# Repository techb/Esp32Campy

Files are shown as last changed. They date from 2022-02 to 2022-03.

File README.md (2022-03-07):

# Esp32Campy
Python implementation for a WebSocket server handling ESP32 Cam module streams. Flask server to handle front-end and house the JS used that does most of the WebSocket work you see. Since this is using a server to handle everything, the limit for concurrent connections, all receiving the live stream and control access, is high.

**This is a fun hobby project and not meant for use in production environments.**

| ABV | == | Abbreviation |
|-----|---|---|
| ESP | == | ESP Cam Module |
| WS  | == | Web Socket |
| FS  | == | Flask Server |

- **WS Server**: Handles the websocket connections. Tracks currently connected clients and removes them when their connections drop. When the WS server receives  messages/data it will echo/resend it to all other connected clients. I wrote it where you need to put in the WS address:port incase you have multiple devices running at once or multi-client connectons. You can connect to the WS of each bot/device/ESP on the network if you know the IP:PORT address.

- **Flask**: Simple flask server handling front-end connections. Serves a single html page containing an img tag for the video data and buttons to control the ESP. This is split up into 3 (three) main places: `static`, `templates`, `classes/FlaskServer.py`. Each containing the respective code. This is the same IP address as the WS server, but a different port.
  - `static`: JavaScript and CSS
  - `templates`: Flask HTML templates
  - `classes/FlaskServer.py`: Flask Server Class

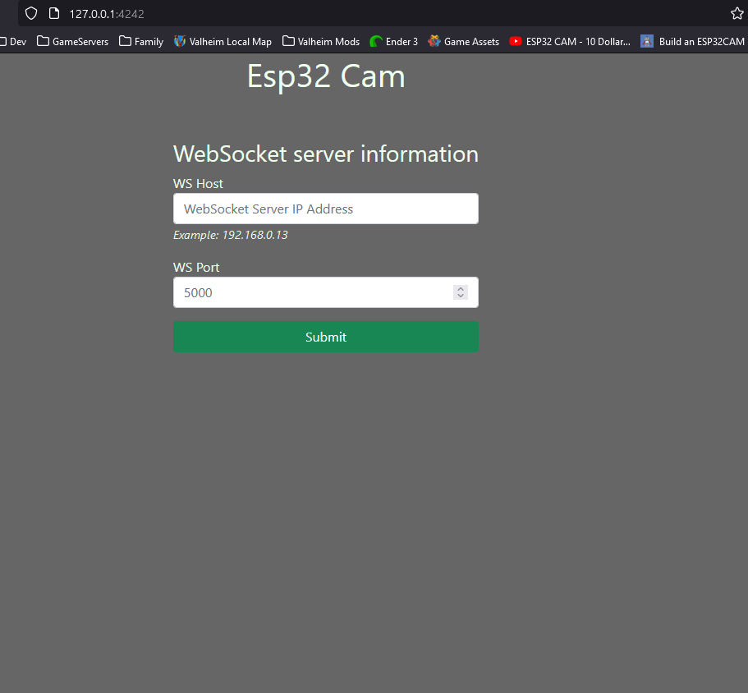
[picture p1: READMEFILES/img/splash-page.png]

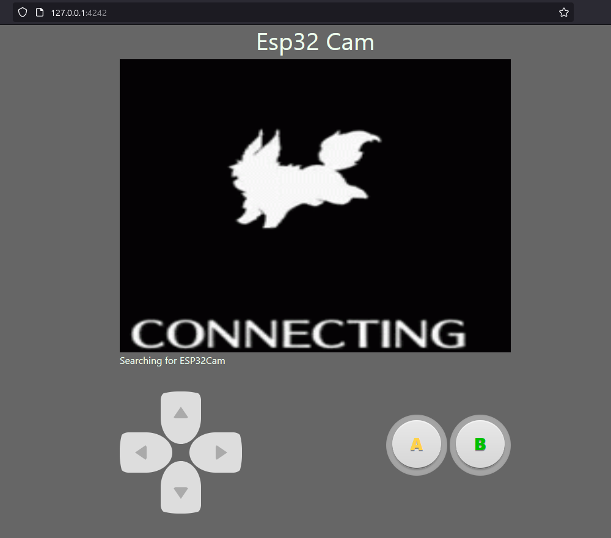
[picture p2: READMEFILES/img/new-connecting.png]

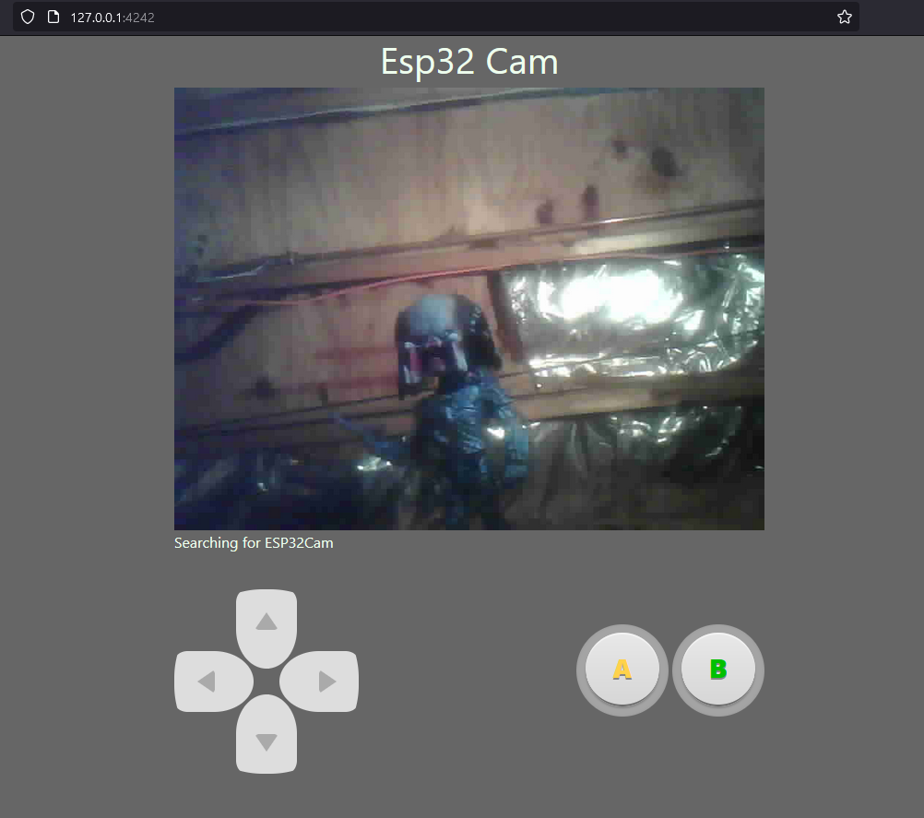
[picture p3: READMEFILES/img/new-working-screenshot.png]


## Software Requirements
- websockets: https://github.com/aaugustin/websockets
- Flask: https://flask.palletsprojects.com/

## Firmware Requirements
- ArduinoJson: https://arduinojson.org/
- Arduino Websockets: https://github.com/gilmaimon/ArduinoWebsockets
- ESP32 Libs & Board manager: https://randomnerdtutorials.com/installing-the-esp32-board-in-arduino-ide-windows-instructions/

## BOM
- ESP32 Cam: https://www.amazon.com/dp/B07S5PVZKV
- USB to FTDI: https://www.sparkfun.com/products/9716
  - You'll need drivers: https://ftdichip.com/drivers/vcp-drivers/
- N20 Motors X2: https://www.amazon.com/gp/product/B07SQ4TV2T
- H-Bridge: https://www.amazon.com/Aideepen-Driver-H-Bridge-Replace-Stepper/dp/B075S368Y2/
- 18640 Batteries X2: https://www.amazon.com/LCLEBM-3400mAh-Battery-Spotlight-Flashlight/dp/B08H1NZLY7

## 3D Print
**--- WARNING! ---**

The .gcode file provided uses a BLTouch.
If you don't use a BLTouch you will need to remove `G29 ; Level bed` in the .gcode file.
There is also OctoLapse comments, those can be ignored if not using OctoLapse, or removed if you prefer your own config.

**----------------**
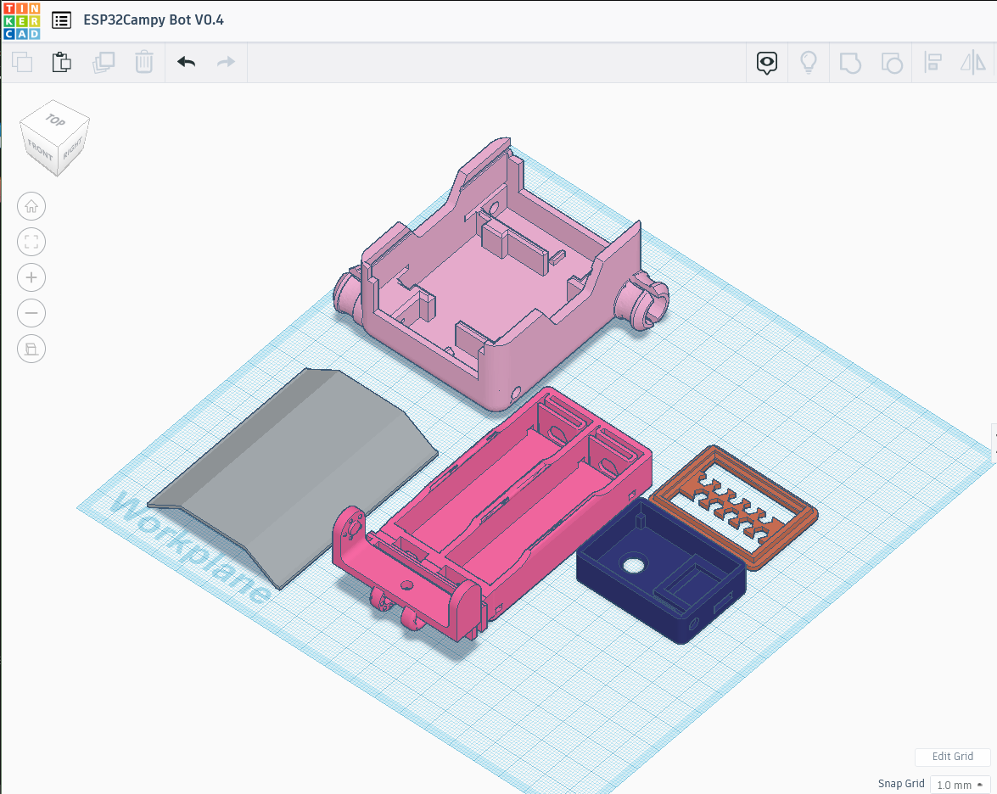
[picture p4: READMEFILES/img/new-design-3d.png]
stl preview 10 hours


#### Remixed From
- cam case: https://www.thingiverse.com/thing:4107609
- 18640 battery holder: https://www.thingiverse.com/thing:2339441
- SMARS robot: https://www.thingiverse.com/thing:2662828

## Schematics
EasyEDA somehow did not save my project... This is the only thing I have from it currently. It is simple enough though. H-Bridge for the motors, voltage regulation, and some optional stuff to make programming easier but not needed (set up for the next project teehee). 

Tripple check connections and cross reference always, I am but a simple man and mess up a lot lol. **Pay attention to orientation and GPIO**
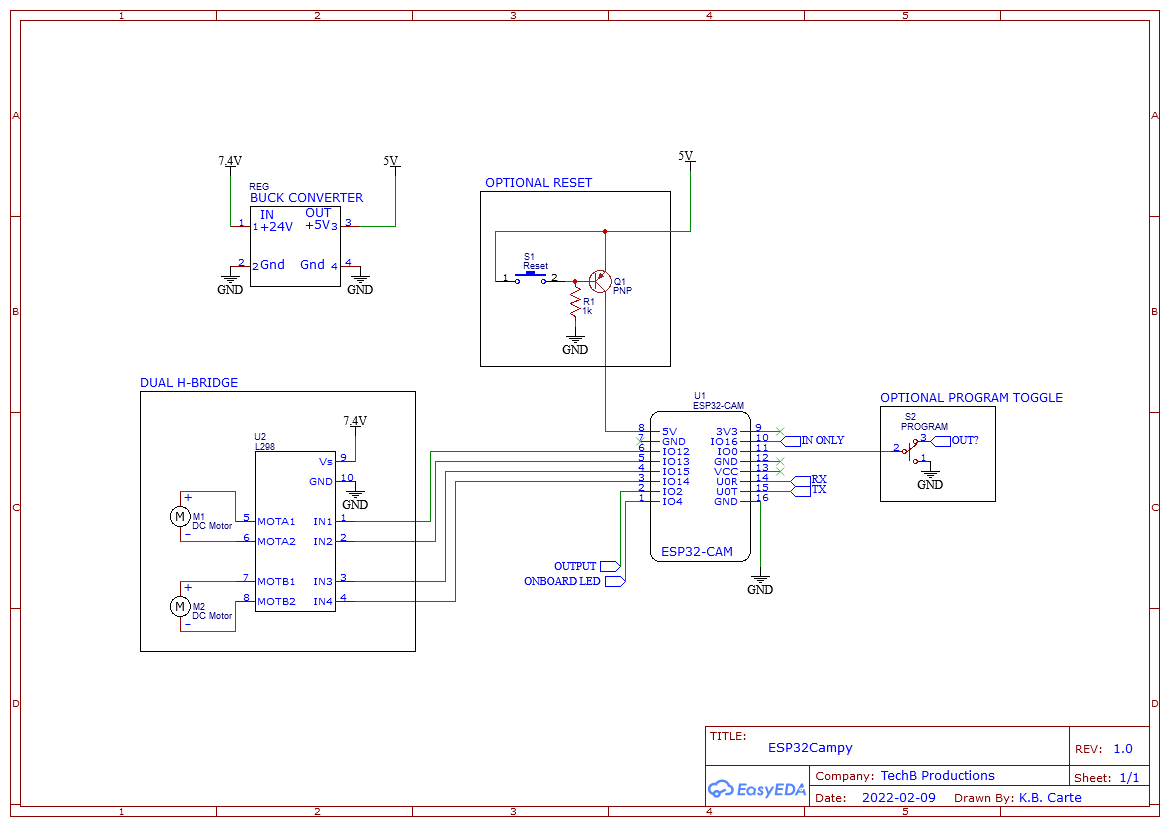
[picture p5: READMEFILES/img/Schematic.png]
image of schematics


## Run
- `$ git clone git@github.com:techb/Esp32Campy.git`
- Ensure you have the required libraries installed for your Arduino IDE
- Upload the `firmware/` code to the ESP32 Cam module via FTDI
  - Change the wifi credentials to be the same network the servers are running on. 
  - You will probably need to make a new Arduino project and save and/or copy the files.
- `$ python -m venv venv`
- `$ venv\Scripts\activate` :: Windows 11/10
  - activating env is dependent on [your OS](https://www.infoworld.com/article/3239675/virtualenv-and-venv-python-virtual-environments-explained.html)
- `$(venv) pip install -r requirements.txt`
- `$(venv) python servers.py`
- Visit your server's IP, if on _this machine/local_ you can use the loopback address
  - default front-end port: `4242`
  - http://127.0.0.1:4242
  - to change default port: edit (WSPORT, FSPORT) in `servers.py` respectively.

## To Do
- Build/Project blog write up
- Clean 3D print files
- Fix mobile
- Hide/Show connecting on disconnect/reconnect of ESP
- Add hosts file for blah.local addresses
- V2 use UART & arduino controlling the low level bot controls like movement. Stay REST-ish, realtime req->parse->bot control

## References
- websockets: https://github.com/aaugustin/websockets
  - docs: https://websockets.readthedocs.io/en/stable/
- great vid, he has more too: https://www.youtube.com/watch?v=SfQd1FdcTlI
- arduino ws broadcast example: https://shorturl.at/akAFG
- loading gif: https://boingboing.net/2015/10/18/loadingicon-trippy-looping-gi.html
- d-pad buttons: https://saruwakakun.com/en/css3-buttons
- AB/XY buttons: https://codepen.io/tswone/pen/GLzZLd
- Bootstrap CSS: https://getbootstrap.com/
- Gamepad support: https://w3c.github.io/gamepad/#remapping
- Gamepad tutorial: https://beej.us/blog/data/javascript-gamepad/
- RX GPIO 3 is always and only an input: https://electronics.stackexchange.com/a/445636

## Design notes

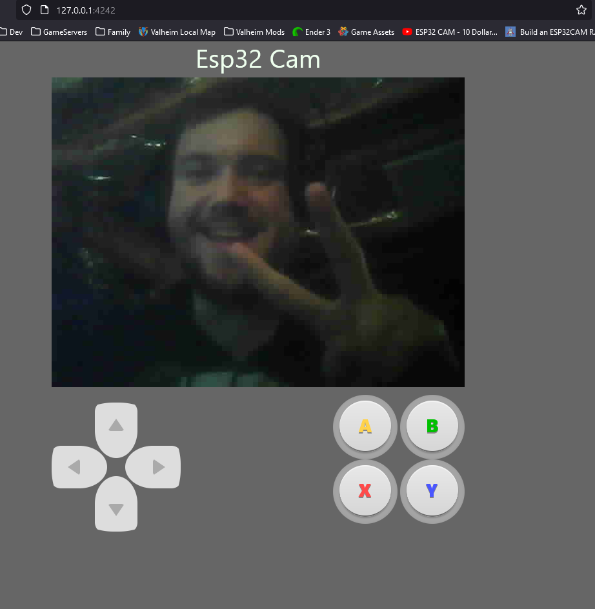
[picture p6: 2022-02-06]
READMEFILES/img/working-stream-low-rez.png

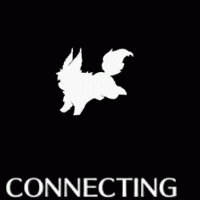
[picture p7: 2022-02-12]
READMEFILES/img/connecting.gif

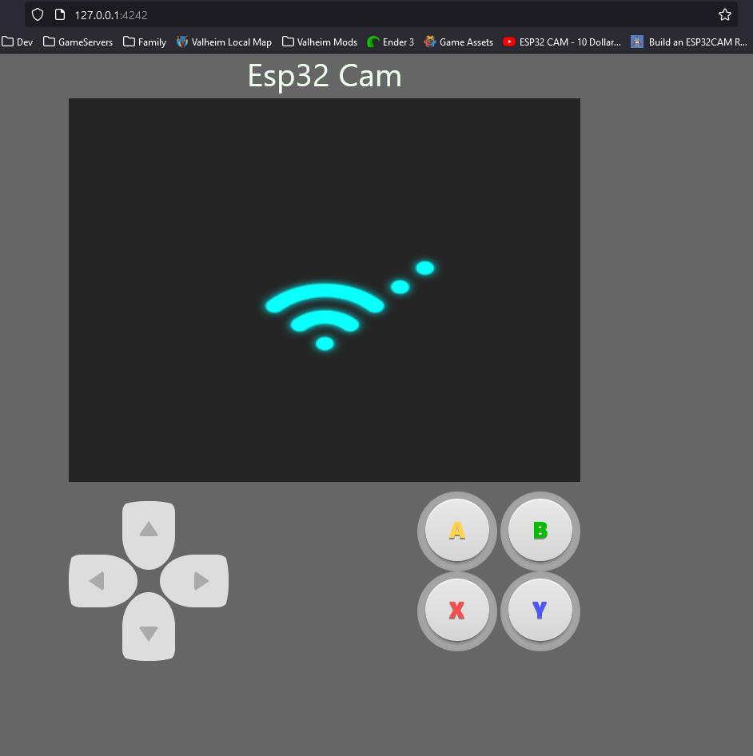
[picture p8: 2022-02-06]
READMEFILES/img/waiting-on-espcam.png

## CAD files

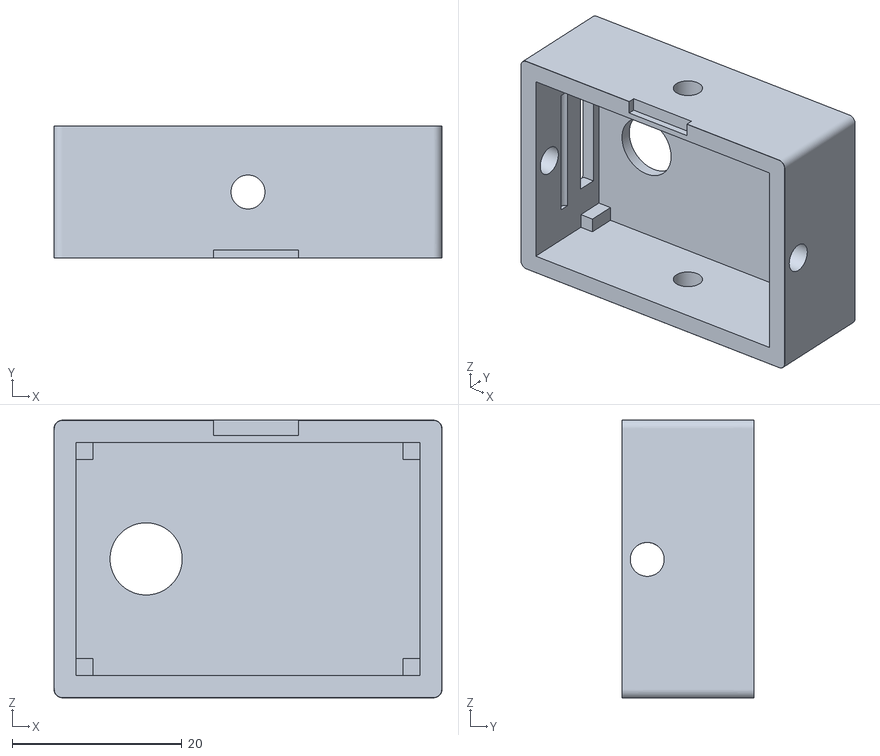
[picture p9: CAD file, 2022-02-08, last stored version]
3DPrint/ESPBot-Cam-Case.stl
45.7 x 15.6 x 32.7

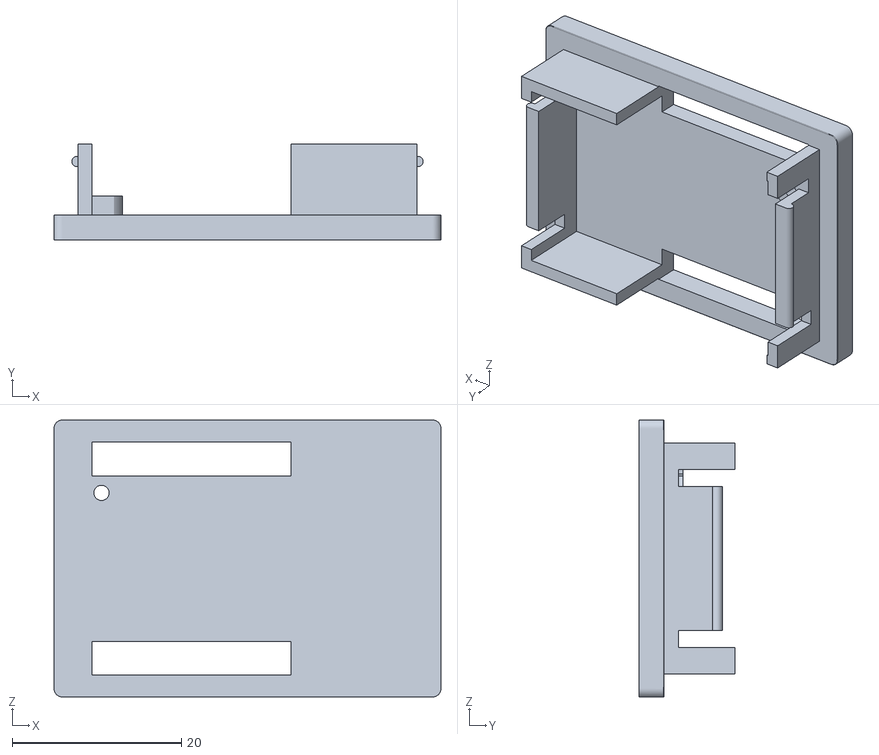
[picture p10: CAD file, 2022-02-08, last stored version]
3DPrint/ESPBot-Cam-Lid.stl
45.7 x 11.4 x 32.7

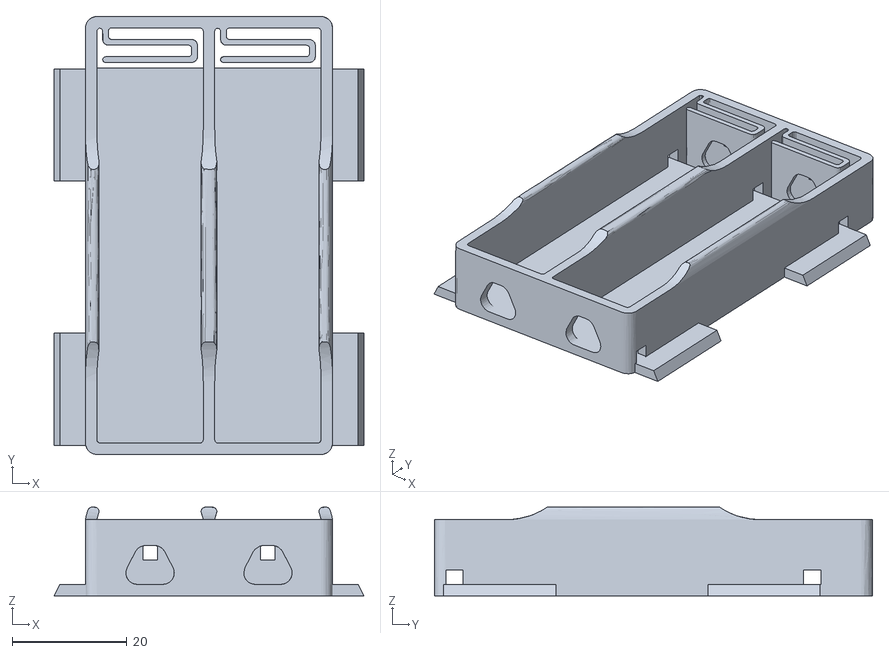
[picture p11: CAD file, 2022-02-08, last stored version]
3DPrint/ESPBot-18650-Holder-X2.stl
53.9 x 76.2 x 15.4

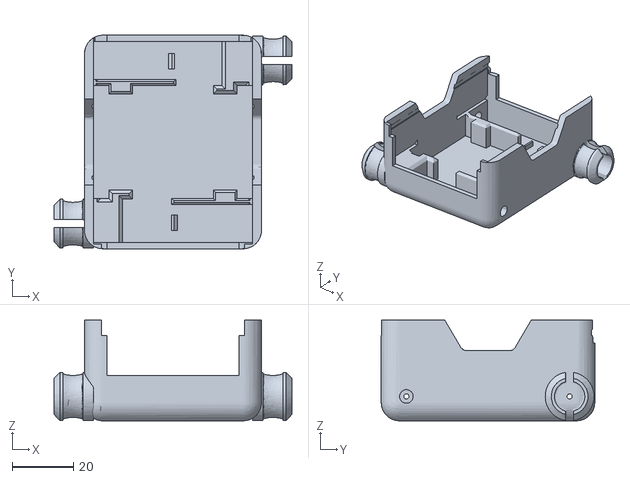
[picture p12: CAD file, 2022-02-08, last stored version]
3DPrint/ESPBot-SMARS-Body.stl
78.0 x 70.0 x 33.0

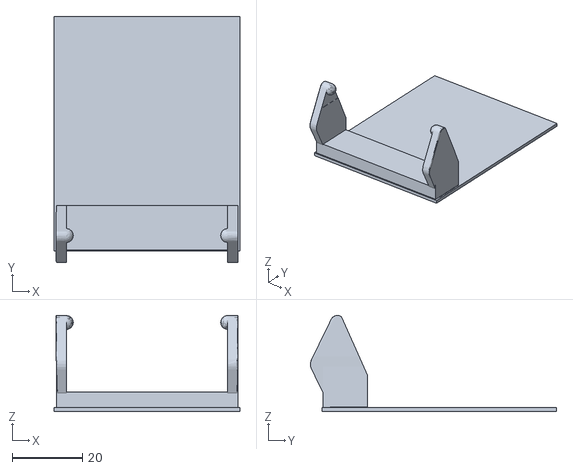
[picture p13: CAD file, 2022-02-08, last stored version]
3DPrint/ESPBot-Swivel-Cam-Holder.stl
53.0 x 70.1 x 27.4

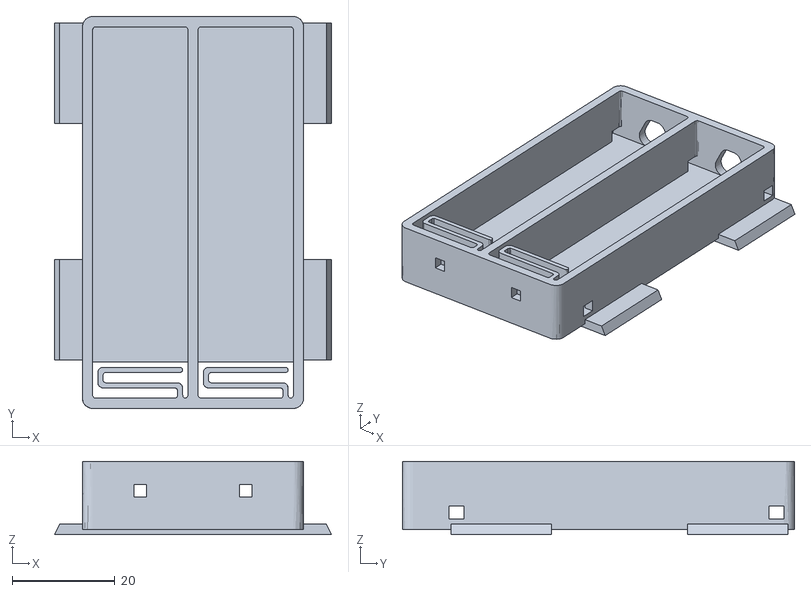
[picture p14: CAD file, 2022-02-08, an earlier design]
3DPrint/ESPBot-18650-Holder-X2-old.stl
53.9 x 76.2 x 14.2

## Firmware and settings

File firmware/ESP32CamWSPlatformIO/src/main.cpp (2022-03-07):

#include "esp_camera.h"
#include <WiFi.h>
#include <Arduino.h>
#include <ArduinoWebsockets.h>
#include <ArduinoJson.h>

// specific to my board yours might be different if
// not using the board listed in the BOM
#define CAMERA_MODEL_AI_THINKER
#include "camera_pins.h"

// network creds and server info
const char *ssid = "Wu Tang LAN";
const char *password = "PostitKnockers";
const char *websocket_server_host = "192.168.0.18";
const uint16_t websocket_server_port = 5000;

// create buffer to receive data comming from other ws clients
StaticJsonDocument<255> jsonBuffer;

// init the websocket client that connects to the ws server
using namespace websockets;
WebsocketsClient client;

// quick and dirty for now
// needs refactor and PWM for movement
void forward()
{
  digitalWrite(12, HIGH);
  digitalWrite(13, LOW);
  digitalWrite(15, HIGH);
  digitalWrite(14, LOW);
}
void reverse()
{
  digitalWrite(12, LOW);
  digitalWrite(13, HIGH);
  digitalWrite(15, LOW);
  digitalWrite(14, HIGH);
}
void hault()
{
  digitalWrite(12, LOW);
  digitalWrite(13, LOW);
  digitalWrite(15, LOW);
  digitalWrite(14, LOW);
}
void left()
{
  digitalWrite(12, LOW);
  digitalWrite(13, HIGH);
  digitalWrite(15, HIGH);
  digitalWrite(14, LOW);
}
void right()
{
  digitalWrite(12, HIGH);
  digitalWrite(13, LOW);
  digitalWrite(15, LOW);
  digitalWrite(14, HIGH);
}
void a_button_on()
{
  digitalWrite(2, HIGH);
}
void a_button_off()
{
  digitalWrite(2, LOW);
}
void b_button_on()
{
  digitalWrite(4, HIGH);
}
void b_button_off()
{
  digitalWrite(4, LOW);
}

void setup()
{
  Serial.begin(115200);
  // Serial.setDebugOutput(true);

  // set camera pins and settings
  camera_config_t config;
  config.ledc_channel = LEDC_CHANNEL_0;
  config.ledc_timer = LEDC_TIMER_0;
  config.pin_d0 = Y2_GPIO_NUM;
  config.pin_d1 = Y3_GPIO_NUM;
  config.pin_d2 = Y4_GPIO_NUM;
  config.pin_d3 = Y5_GPIO_NUM;
  config.pin_d4 = Y6_GPIO_NUM;
  config.pin_d5 = Y7_GPIO_NUM;
  config.pin_d6 = Y8_GPIO_NUM;
  config.pin_d7 = Y9_GPIO_NUM;
  config.pin_xclk = XCLK_GPIO_NUM;
  config.pin_pclk = PCLK_GPIO_NUM;
  config.pin_vsync = VSYNC_GPIO_NUM;
  config.pin_href = HREF_GPIO_NUM;
  config.pin_sscb_sda = SIOD_GPIO_NUM;
  config.pin_sscb_scl = SIOC_GPIO_NUM;
  config.pin_pwdn = PWDN_GPIO_NUM;
  config.pin_reset = RESET_GPIO_NUM;
  config.xclk_freq_hz = 10000000;
  config.pixel_format = PIXFORMAT_JPEG;

  // init with high specs to pre-allocate larger buffers
  config.frame_size = FRAMESIZE_VGA;
  config.jpeg_quality = 40;
  config.fb_count = 2;

  // camera init
  esp_err_t err = esp_camera_init(&config);
  if (err != ESP_OK)
  {
    Serial.printf("Camera init failed with error 0x%x", err);
    return;
  }

  // connect to wifi
  WiFi.begin(ssid, password);
  while (WiFi.status() != WL_CONNECTED)
  {
    delay(500);
    Serial.print(".");
  }
  Serial.println("");
  Serial.println("WiFi connected");

  // connect to websocket
  Serial.println("Attempting WebSocket Connection");
  while (!client.connect(websocket_server_host, websocket_server_port, "/"))
  {
    delay(500);
    Serial.print(".");
  }
  Serial.println("Websocket Connected!");

  int res = 0;
  sensor_t *s = esp_camera_sensor_get();
  res = s->set_framesize(s, (framesize_t)9);

  // handle json data from web interface
  // handle_json is the callback where the actual,
  //   logic lives when recieving websocket messages
  // the auto formatting on save, is ugly af...
  client.onMessage([](WebsocketsMessage msg)
                   {
    String raw_data = msg.data();
    handle_json(raw_data); });

  pinMode(12, OUTPUT); // IN1 MA
  pinMode(13, OUTPUT); // IN2 MA
  pinMode(15, OUTPUT); // IN3 MB
  pinMode(14, OUTPUT); // IN4 MB
  pinMode(2, OUTPUT);  // A
  pinMode(4, OUTPUT);  // B

  // set everything low so the bot doesn't go crazy on startup
  digitalWrite(12, LOW);
  digitalWrite(13, LOW);
  digitalWrite(15, LOW);
  digitalWrite(14, LOW);
  digitalWrite(2, LOW);
  digitalWrite(4, LOW);
}

// handle incoming websocket messages
void handle_json(String raw_data)
{
  DeserializationError error = deserializeJson(jsonBuffer, raw_data);
  if (error)
  {
    Serial.print(F("deserializeJson() failed: "));
    Serial.println(error.f_str());
    return;
  }

  // quick and dirty for now
  // needs refactor
  const char *message = jsonBuffer["message"];

  // check message sent and deligate functions to execute
  if (strcmp(message, "forward") == 0)
  {
    forward();
  }
  if (strcmp(message, "reverse") == 0)
  {
    reverse();
  }
  if (strcmp(message, "hault") == 0)
  {
    hault();
  }
  if (strcmp(message, "left") == 0)
  {
    left();
  }
  if (strcmp(message, "right") == 0)
  {
    right();
  }

  if (strcmp(message, "AON") == 0)
  {
    a_button_on();
  }
  if (strcmp(message, "AOFF") == 0)
  {
    a_button_off();
  }
  if (strcmp(message, "BON") == 0)
  {
    b_button_on();
  }
  if (strcmp(message, "BOFF") == 0)
  {
    b_button_off();
  }
}

void loop()
{
  // check for any incoming messages
  client.poll();

  // get new image from camera
  camera_fb_t *fb = esp_camera_fb_get();
  if (!fb)
  {
    Serial.println("Camera capture failed");
    esp_camera_fb_return(fb);
    return;
  }

  // check it's in jpeg, needed I think for the raw blob binary?
  if (fb->format != PIXFORMAT_JPEG)
  {
    Serial.println("Non-JPEG data not implemented");
    return;
  }

  // send to websocket
  client.sendBinary((const char *)fb->buf, fb->len);
  esp_camera_fb_return(fb);
}

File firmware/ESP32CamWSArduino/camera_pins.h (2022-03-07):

#define PWDN_GPIO_NUM     32
#define RESET_GPIO_NUM    -1
#define XCLK_GPIO_NUM      0
#define SIOD_GPIO_NUM     26
#define SIOC_GPIO_NUM     27
#define Y9_GPIO_NUM       35
#define Y8_GPIO_NUM       34
#define Y7_GPIO_NUM       39
#define Y6_GPIO_NUM       36
#define Y5_GPIO_NUM       21
#define Y4_GPIO_NUM       19
#define Y3_GPIO_NUM       18
#define Y2_GPIO_NUM        5
#define VSYNC_GPIO_NUM    25
#define HREF_GPIO_NUM     23
#define PCLK_GPIO_NUM     22

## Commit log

2022-02-07 develop :: ws talking to esp32
2022-02-08 develop :: added gamepad support, rx is input only so we lost the X button, stls added
    [ESPBot-18650-Holder-X2-old.stl, ESPBot-18650-Holder-X2.stl, ESPBot-Cam-Case.stl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]
2022-02-12 develop :: edit README, new 3D print, cleaned things a touch
    [ESPBot-18650-Holder-X2-old.stl, ESPBot-18650-Holder-X2.stl]
2022-02-12 develop :: I need to go to bed
2022-03-07 develop :: removed gcode
    [ESPBot-Cam-Case.stl, ESPBot-Cam-Lid.stl, ESPBot-SMARS-Body.stl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]
